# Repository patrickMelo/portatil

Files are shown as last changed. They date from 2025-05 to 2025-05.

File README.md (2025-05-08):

# Portatil

A "made-real" fantasy retro gaming console.

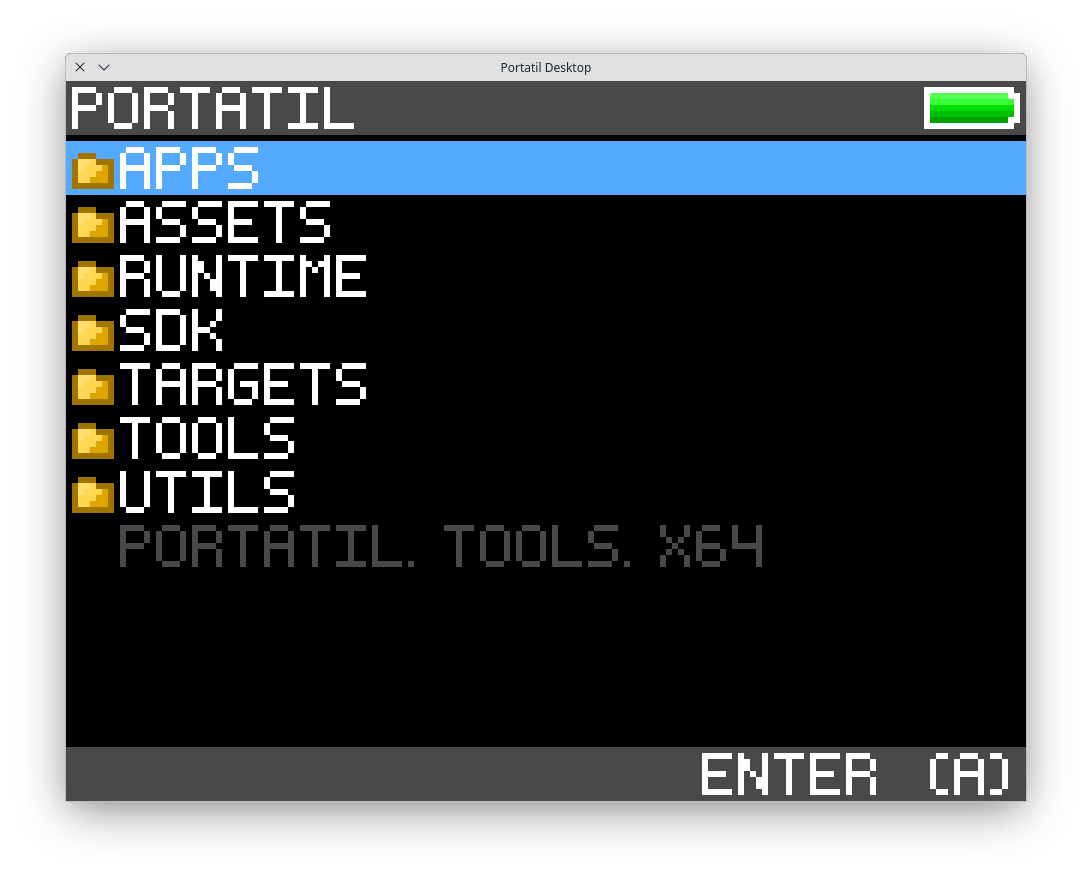
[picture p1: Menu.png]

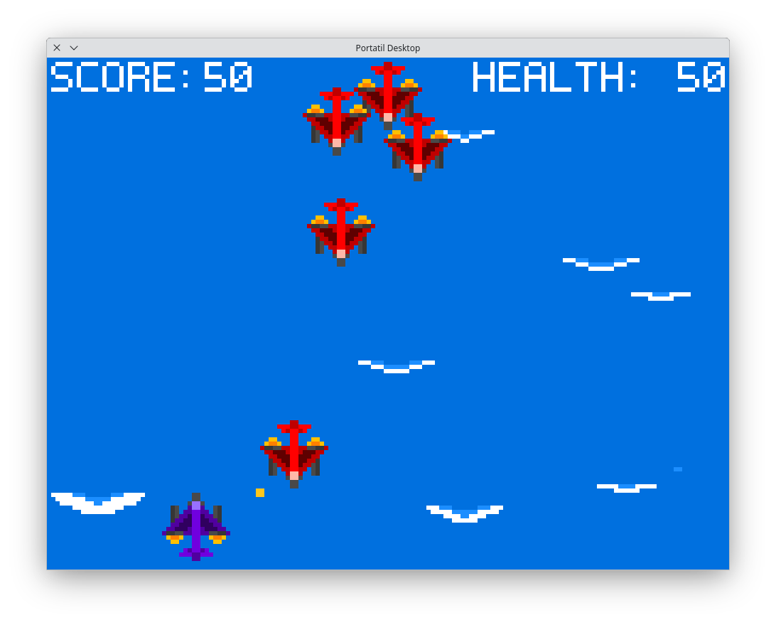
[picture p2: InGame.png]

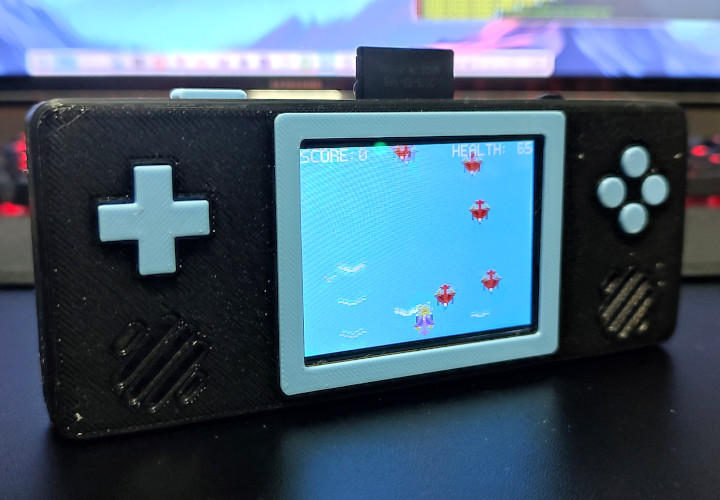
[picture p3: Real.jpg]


Portatil is a virtual machine based gaming console that runs RISC-V applications with custom system calls.

Runtimes can be easily ported to new targets by implementing specific drivers as kernel and engine code are target agnostic. Currently there are runtimes for Linux/SDL (mainly for development) and RaspiberryPi Pico (using RP2040 Zero from Waveshare).

## Virtual Machine Specifications

- CPU: RV32I instruction set (with custom fixed point math library).
- Memory: 32KB of RAM.
- Input: 8 digital inputs (left, right, up, down, a, b, x, y).
- Graphics: 160x120, 256 color framebuffer.
- Sound: 4 channel, 22KHz, 8-bit wave generator (sawtooth, square and triangle waves).
- 2D Engine: 4 layers, 256 sprites total, 128 entities on screen, basic physics simulation.
- Storage: FAT-32 formatted SD cards (read-only).

## Directory Structure

```sh
-- 3D Parts/    # 3D printable console shell
---- STL/       # exported parts for printing
-- Docs/        # hardware and software reference
-- Hardware/    # schematics and PCB design
-- Software/    # runtime and tools
---- Apps/      # demo application
---- Assets/    # runtime assets
---- Runtime/   # runtime code
------ Drivers/ # target specific code/drivers
------ States/  # high-level runtime code
---- SDK/       # C SDK
---- Targets/   # runtime targets
---- Tools/     # development tools
---- Utils/     # utilities
```

## TODO

There is still a lot of things to be done:
- Add actually usefull documentation to this repository;
- Create boilerplate code for new games;
- Write a tutorial on how to create your first game;
- Implement a Windows/SDL runtime;
- Add support for Windows based toolchains (to be able to compile games in Windows);
- Implement FAT-32 writing support;
- Add support for game saving;
- Add support for game thumbnails;

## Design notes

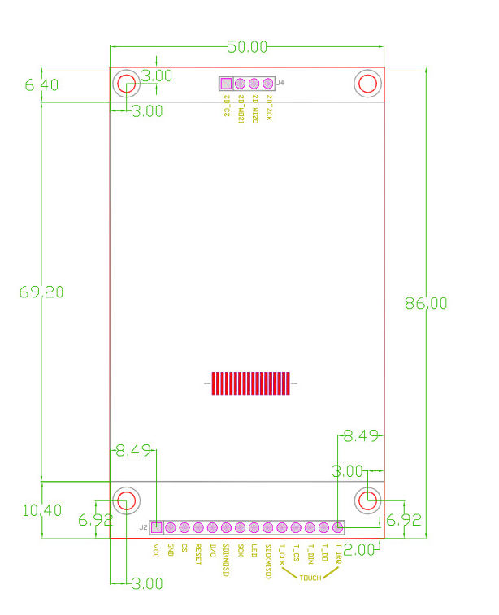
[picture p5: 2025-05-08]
Docs/LCD Module Dimensions.png

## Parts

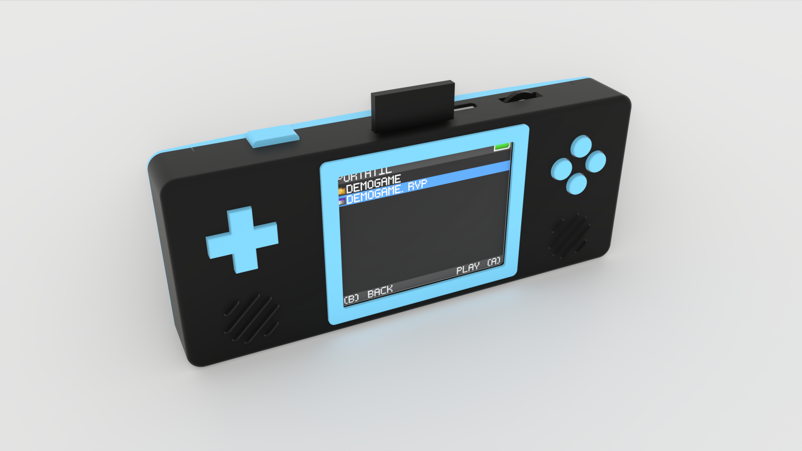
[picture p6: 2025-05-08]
3D Parts/Renders/Front.png

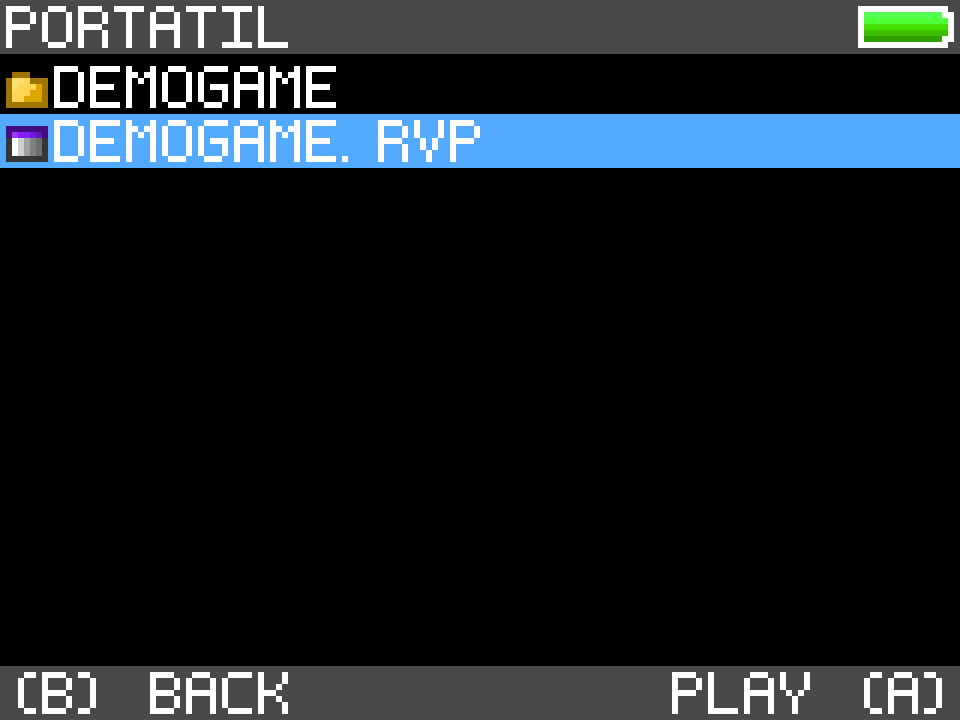
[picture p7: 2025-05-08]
3D Parts/Screenshot.png

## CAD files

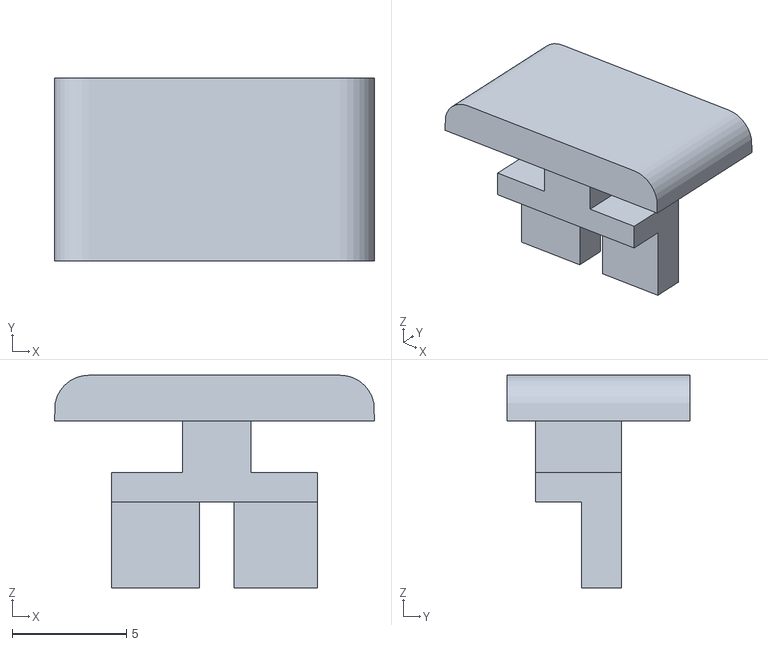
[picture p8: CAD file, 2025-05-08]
3D Parts/STL/Power Slider.stl
14.0 x 8.00 x 9.30

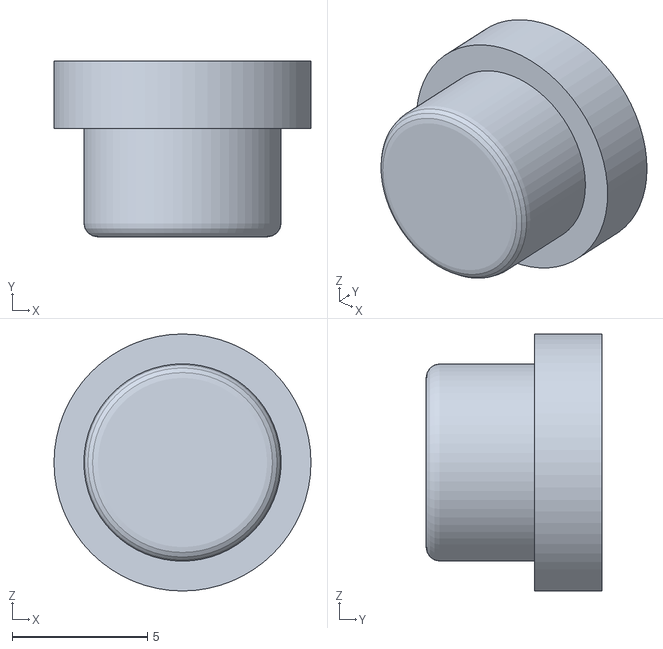
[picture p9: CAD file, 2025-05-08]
3D Parts/STL/Button.stl
9.50 x 6.50 x 9.50

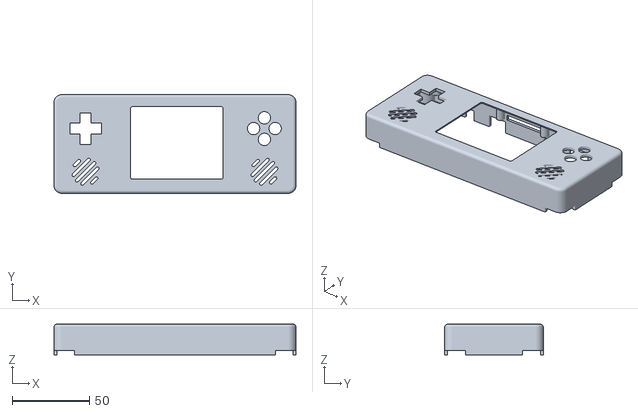
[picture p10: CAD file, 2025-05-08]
3D Parts/STL/Shell - Front.stl
157.0 x 64.0 x 20.0

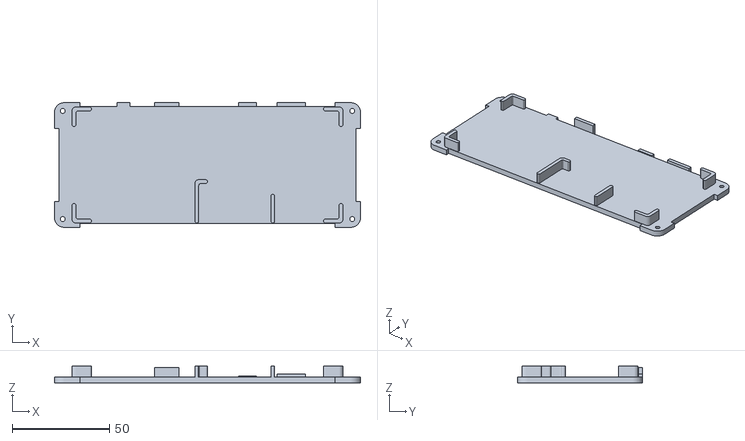
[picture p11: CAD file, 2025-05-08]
3D Parts/STL/Shell - Back.stl
157.0 x 64.0 x 8.50

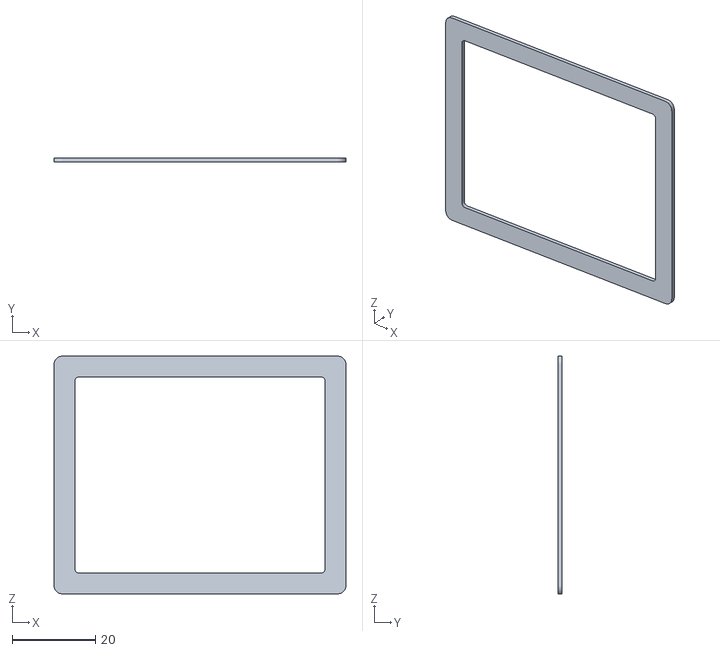
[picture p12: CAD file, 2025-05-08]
3D Parts/STL/Front Plate.stl
70.0 x 1.00 x 57.0

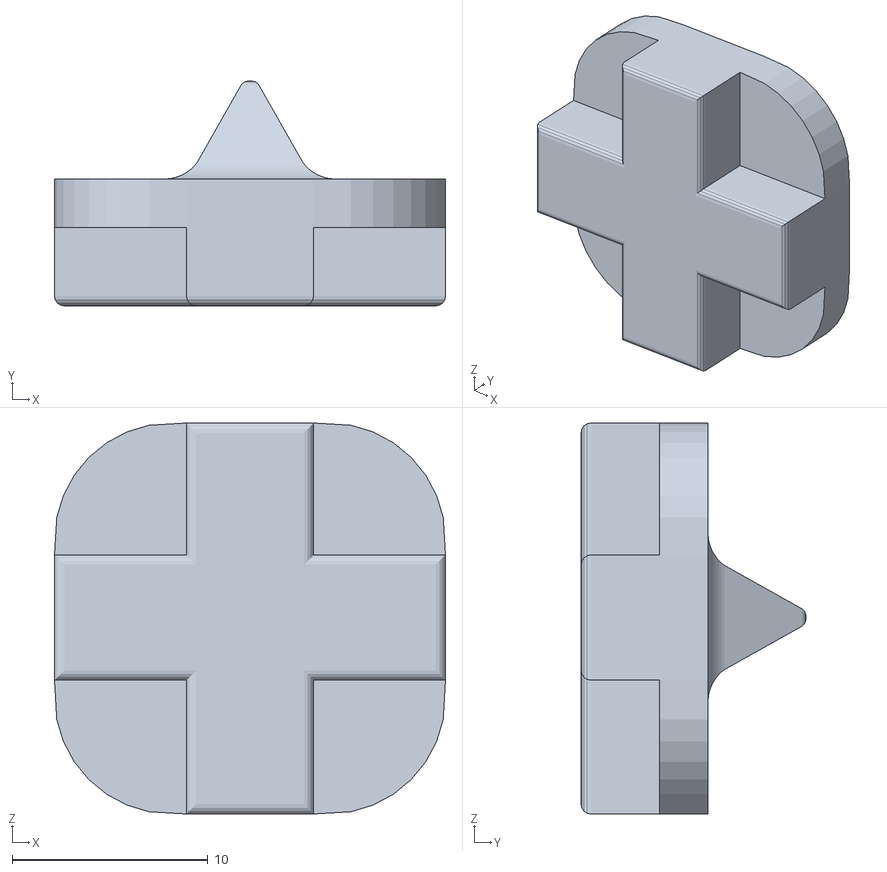
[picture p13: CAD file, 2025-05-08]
3D Parts/STL/DPad.stl
20.0 x 11.5 x 20.0

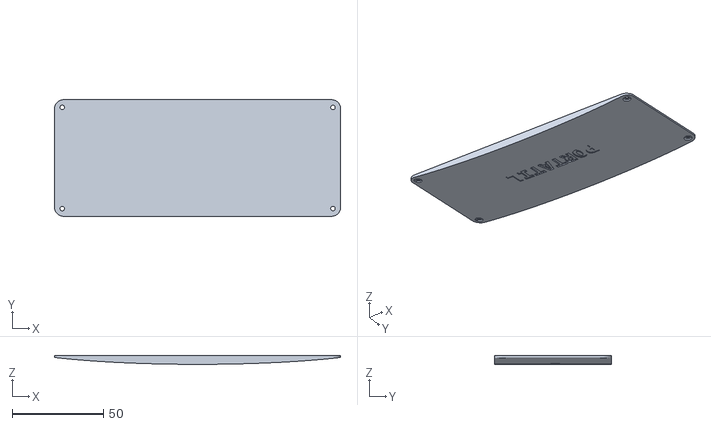
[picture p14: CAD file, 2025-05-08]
3D Parts/STL/Back Plate.stl
156.9 x 64.0 x 4.79

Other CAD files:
3D Parts/Portatil.blend

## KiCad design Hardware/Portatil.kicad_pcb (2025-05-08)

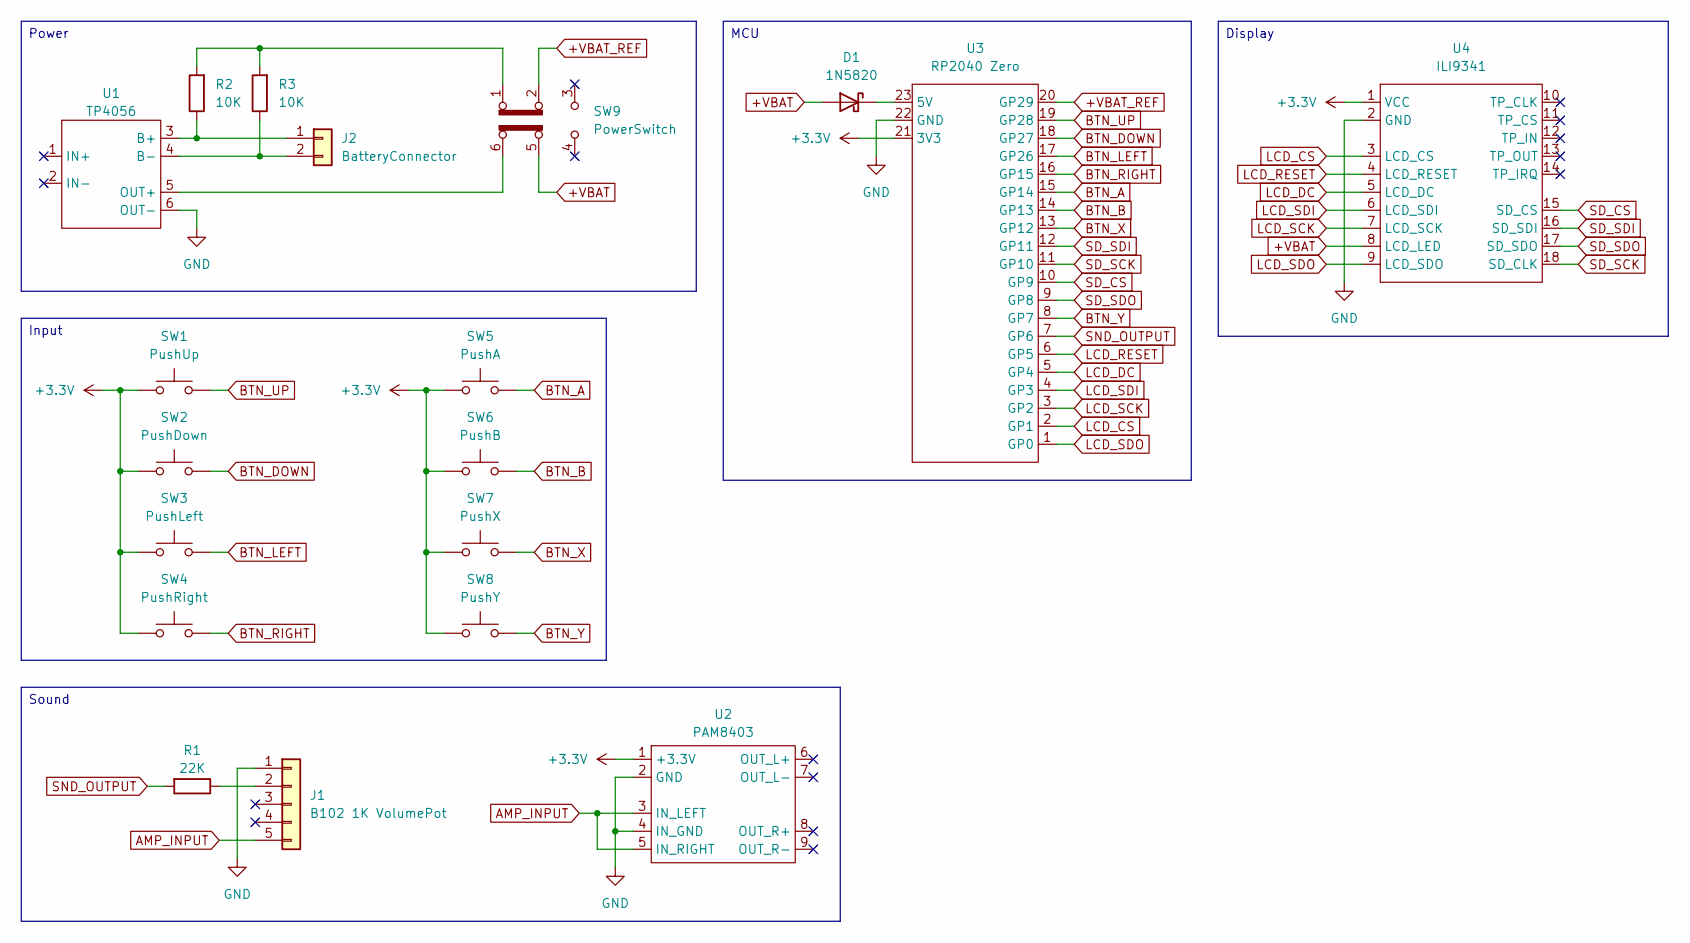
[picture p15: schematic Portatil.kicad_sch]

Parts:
D1: 1N5820; D_DO-35_SOD27_P7.62mm_Horizontal
J1: B102 1K VolumePot; Thumbwheel Potentiometer
J2: BatteryConnector; PinSocket_1x02_P2.54mm_Vertical
R1: 22K; R_Axial_DIN0207_L6.3mm_D2.5mm_P10.16mm_Horizontal
R2, R3: 10K; R_Axial_DIN0207_L6.3mm_D2.5mm_P10.16mm_Horizontal
SW1: PushUp; SW_PUSH_6mm
SW2: PushDown; SW_PUSH_6mm
SW3: PushLeft; SW_PUSH_6mm
SW4: PushRight; SW_PUSH_6mm
SW5: PushA; SW_PUSH_6mm
SW6: PushB; SW_PUSH_6mm
SW7: PushX; SW_PUSH_6mm
SW8: PushY; SW_PUSH_6mm
SW9: PowerSwitch; SW_CK_JS202011CQN_DPDT_Straight
U1: TP4056; TP4056 Module
U2: PAM8403; PAM8403 Module
U3: RP2040 Zero
U4: ILI9341; ILI9341 Module

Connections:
+3.3V: SW1.1, SW2.1, SW3.1, SW4.1, SW5.1, SW6.1, SW7.1, SW8.1, U2.1 (+3.3V), U3.21 (3V3), U4.1 (VCC)
+VBAT: D1.2 (A), SW9.5 (B), U4.8 (LCD_LED)
+VBAT_REF: SW9.2 (B), U3.20 (GP29)
AMP_INPUT: J1.5, U2.3 (IN_LEFT), U2.5 (IN_RIGHT)
BTN_A: SW5.2, U3.15 (GP14)
BTN_B: SW6.2, U3.14 (GP13)
BTN_DOWN: SW2.2, U3.18 (GP27)
BTN_LEFT: SW3.2, U3.17 (GP26)
BTN_RIGHT: SW4.2, U3.16 (GP15)
BTN_UP: SW1.2, U3.19 (GP28)
BTN_X: SW7.2, U3.13 (GP12)
BTN_Y: SW8.2, U3.8 (GP7)
GND: J1.1, U1.6 (OUT-), U2.2 (GND), U2.4 (IN_GND), U3.22 (GND), U4.2 (GND)
LCD_CS: U3.2 (GP1), U4.3 (LCD_CS)
LCD_DC: U3.5 (GP4), U4.5 (LCD_DC)
LCD_RESET: U3.6 (GP5), U4.4 (LCD_RESET)
LCD_SCK: U3.3 (GP2), U4.7 (LCD_SCK)
LCD_SDI: U3.4 (GP3), U4.6 (LCD_SDI)
LCD_SDO: U3.1 (GP0), U4.9 (LCD_SDO)
unnamed: D1.1 (K), U3.23 (5V)
unnamed: J1.2, R1.1
unnamed: J2.1, R2.1, U1.3 (B+)
unnamed: J2.2, R3.1, U1.4 (B-)
unnamed: R2.2, R3.2, SW9.1 (A)
unnamed: SW9.6 (C), U1.5 (OUT+)
SD_CS: U3.10 (GP9), U4.15 (SD_CS)
SD_SCK: U3.11 (GP10), U4.18 (SD_CLK)
SD_SDI: U3.12 (GP11), U4.16 (SD_SDI)
SD_SDO: U3.9 (GP8), U4.17 (SD_SDO)
SND_OUTPUT: R1.2, U3.7 (GP6)

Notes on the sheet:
Sound
MCU
Input
Display
Power

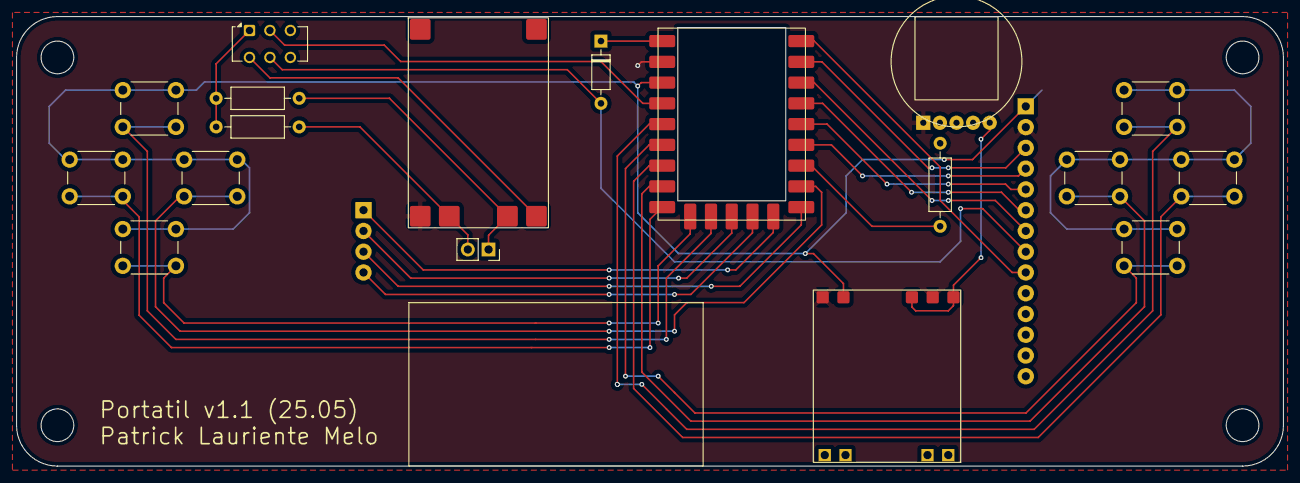
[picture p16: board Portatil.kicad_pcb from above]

Board: 2 copper layers, 155.0 x 55.0 mm, 19 parts (1 on the bottom side), 30 nets.

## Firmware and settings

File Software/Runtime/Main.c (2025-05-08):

//
// Runtime/Main.c
//
// This file is part of Portatil source code.
// Copyright 2025 Patrick L. Melo <patrick@patrickmelo.com.br>
//

#include "Engine.h"
#include "Kernel.h"
#include "States.h"
#include "VM.h"

#define bootSplashTime 1000000

static bool bootSplashDrawn = false;

static void bootFunction(const u64 frameTime) {
    if (!bootSplashDrawn) {
        bootSplashDrawn = true;

        ClearScreen(0);
        SetTransparentColor(0);
        SetDrawAnchor(AnchorMiddle | AnchorCenter);
        DrawText(GetDefaultFont(), ScreenWidth / 2, ScreenHeight / 2, "Portatil");

        return;
    }

    Sleep(bootSplashTime);

    InitializeError();
    InitializeShell();
    InitializeInGame();
    InitializeVirtualMachine();
    InitializeEngine();

    ChangeState(ShellState);
}

int main(const int numberOfArguments, const string* argumentsValues) {
    return Boot(bootFunction) ? 0 : 1;
}

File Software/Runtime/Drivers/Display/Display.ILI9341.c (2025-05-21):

//
// Runtime/Drivers/Display/Display.ILI9341.c
//
// This file is part of Portatil source code.
// Copyright 2025 Patrick L. Melo <patrick@patrickmelo.com.br>
//

#include "../../Drivers.h"

// Serial ---------------------------------------------------------------------

#define serialPortNumber SerialPort0
#define serialSpeed      62500000

#define dcPin    4
#define resetPin 5

static const u8 cmdNop                  = 0x00;
static const u8 cmdSoftwareReset        = 0x01;
static const u8 cmdSleep                = 0x10;
static const u8 cmdWakeUp               = 0x11;
static const u8 cmdDisplayOff           = 0x28;
static const u8 cmdDisplayOn            = 0x29;
static const u8 cmdSetColumnAddress     = 0x2A;
static const u8 cmdSetPageAddress       = 0x2B;
static const u8 cmdWriteMemory          = 0x2C;
static const u8 cmdMemoryAccessControl  = 0x36;
static const u8 cmdSetPixelFormat       = 0x3A;
static const u8 cmdNormalFrameControl   = 0xB1;
static const u8 cmdFunctionControl      = 0xB6;
static const u8 cmdPowerControl1        = 0xC0;
static const u8 cmdPowerControl2        = 0xC1;
static const u8 cmdVCOMControl1         = 0xC5;
static const u8 cmdVCOMControl2         = 0xC7;
static const u8 cmdPowerControlA        = 0xCB;
static const u8 cmdPowerControlB        = 0xCF;
static const u8 cmdDriverTimingControlA = 0xE8;
static const u8 cmdDriverTimingControlB = 0xEA;
static const u8 cmdPowerOnSequence      = 0xED;
static const u8 cmdPumpRatioControl     = 0xF7;

#define sendCommand(command)                             \
    DrvGpioDigitalWrite(dcPin, false);                   \
    DrvSerialWrite(serialPortNumber, 1, (u8*) &command); \
    DrvGpioDigitalWrite(dcPin, true);

#define writeData(data, size) DrvSerialWrite(serialPortNumber, size, (u8*) data)

#define writeData8(data)  writeData(&data, 1)
#define writeData16(data) writeData(&data, 2)

#define executeCommand(command, data, size) \
    sendCommand(command);                   \
    writeData(data, size)

static inline void setAddress(const u16 x0,
                              const u16 y0,
                              const u16 x1,
                              const u16 y1) {
    u16 sx0 = (x0 << 8) | (x0 >> 8);
    u16 sx1 = (x1 << 8) | (x1 >> 8);
    u16 sy0 = (y0 << 8) | (y0 >> 8);
    u16 sy1 = (y1 << 8) | (y1 >> 8);

    sendCommand(cmdSetColumnAddress);
    writeData16(sx0);
    writeData16(sx1);

    sendCommand(cmdSetPageAddress);
    writeData16(sy0);
    writeData16(sy1);
}

static bool initializeDisplay(void) {
    if (!DrvGpioConfigure(resetPin, GpioDigital, GpioOutput)) {
        return false;
    }

    if (!DrvGpioConfigure(dcPin, GpioDigital, GpioOutput)) {
        return false;
    }

    DrvGpioDigitalWrite(resetPin, 0);
    Sleep(50000);
    DrvGpioDigitalWrite(resetPin, 1);
    Sleep(50000);

    sendCommand(cmdDisplayOff);
    sendCommand(cmdSoftwareReset);

    executeCommand(cmdPowerControlB, "\x00\xC1\x30", 3);
    executeCommand(cmdPowerOnSequence, "\x64\x03\x12\x81", 4);
    executeCommand(cmdDriverTimingControlA, "\x85\x00\x78", 3);
    executeCommand(cmdPowerControlA, "\x39\x2C\x00\x34\x02", 5);
    executeCommand(cmdPumpRatioControl, "\x20", 1);
    executeCommand(cmdDriverTimingControlB, "\x00\x00", 2);
    executeCommand(cmdPowerControl1, "\x23", 1);
    executeCommand(cmdPowerControl2, "\x10", 1);
    executeCommand(cmdVCOMControl1, "\x3E\x28", 2);
    executeCommand(cmdVCOMControl2, "\x86", 1);
    executeCommand(cmdFunctionControl, "\x08\x82\x27\x00", 4);
    executeCommand(cmdMemoryAccessControl, "\xE8", 1);       // Rotated 90 Degrees
    executeCommand(cmdSetPixelFormat, "\x55", 1);            // 16-bit Colors
    executeCommand(cmdNormalFrameControl, "\x00\x10", 2);    // 119Hz

    sendCommand(cmdWakeUp);
    Sleep(50000);
    sendCommand(cmdDisplayOn);
    Sleep(50000);

    return true;
}

void finalizeDisplay(void) {
    sendCommand(cmdSleep);
    Sleep(50000);
    sendCommand(cmdDisplayOff);
    Sleep(50000);
}

// Display --------------------------------------------------------------------

#define displayWidth  320
#define displayHeight 240

#define blitRows   12
#define blitWidth  displayWidth
#define blitHeight (displayHeight / blitRows)
#define blitPixels (blitWidth * blitHeight)

static u16 blitBuffer[blitPixels];
static u8  localFrameBuffer[ScreenPixels];
static u16 displayColorPalette[ScreenColors * 3];
static u8  coreIndex;

static u64 lastSyncTick = 0;
static u64 busyTime     = 0;

static inline u16 toDisplayColor(const u8* color) {
    // RRRRR GGGGGG BBBBB
    u16 displayColor = ((color[0] >> 3) << 11) |
                       ((color[1] >> 2) << 5) |
                       ((color[2] >> 3));

    return (displayColor << 8) | (displayColor >> 8);
}

static inline void fillBlitBuffer(const u32 startY) {
    static u32 pixelIndex;
    static u16 pixelColor;
    static u32 lineStart;

    for (u16 pixelY = 0; pixelY < blitHeight / 2; pixelY++) {
        lineStart = ((startY + pixelY) * ScreenWidth);

        for (u16 pixelX = 0; pixelX < ScreenWidth; pixelX++) {
            pixelIndex = lineStart + pixelX;
            pixelColor = displayColorPalette[localFrameBuffer[pixelIndex]];

            blitBuffer[(pixelY * 2 * blitWidth) + (pixelX * 2)]           = pixelColor;
            blitBuffer[(pixelY * 2 * blitWidth) + (pixelX * 2 + 1)]       = pixelColor;
            blitBuffer[((pixelY * 2 + 1) * blitWidth) + (pixelX * 2)]     = pixelColor;
            blitBuffer[((pixelY * 2 + 1) * blitWidth) + (pixelX * 2 + 1)] = pixelColor;
        }
    }
}

void syncCore(void) {
    for (;;) {
        DrvCpuWaitMessage(coreIndex, NULL);

        u64 startTime = DrvCpuGetTick();

        if (startTime - lastSyncTick > TargetFrameTime) {
            continue;
        }

        DrvSerialWait(serialPortNumber);

        setAddress(0, 0, displayWidth - 1, displayHeight - 1);
        sendCommand(cmdWriteMemory);

        u16 pixelY = 0;

        for (u8 rowIndex = 0; rowIndex < blitRows; rowIndex++) {
            DrvSerialWait(serialPortNumber);
            fillBlitBuffer(pixelY);
            pixelY += blitHeight / 2;

            DrvSerialWrite(serialPortNumber, blitPixels * 2, (u8*) blitBuffer);
        }

        busyTime = DrvCpuGetTick() - startTime;
    }
}

// Driver ---------------------------------------------------------------------

bool DrvDisplayInitialize(void) {
    if (!DrvSerialConfigure(serialPortNumber, serialSpeed, true)) {
        return false;
    }

    if (!initializeDisplay()) {
        return false;
    }

    memset(blitBuffer, 0, blitPixels * 2);

    coreIndex = DrvCpuGetAvailableCoreIndex();

    if ((coreIndex == 0) || !DrvCpuRunCore(coreIndex, 1, 10, syncCore)) {
        finalizeDisplay();
        return false;
    }

    busyTime = 0;
    return true;
}

void DrvDisplayFinalize(void) {
    finalizeDisplay();
}
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
